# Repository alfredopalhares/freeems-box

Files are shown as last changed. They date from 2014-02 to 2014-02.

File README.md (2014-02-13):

FreeEMS Box
===========

A Case to host the FreeEMS capabable boards, to keep all that deterministic horse power safe !

Supported Boards
----------------

- [Jaguar](https://github.com/DeuceEFI/Jaguar) Work in progress

License
-------

The License is [MIT](http://opensource.org/licenses/MIT) with a flavour of beerware, if you use this
this you *must* pay me a beer or you shall be cursed by the Gods of Speed :)

Authors and Copyright
---------------------

- Alfredo Palhares (masterkorp@masterkorp.net) and masterkorp on irc.freenode.org

The molex connectors data sheets and all the related informations is copyright of Molex, Inc.

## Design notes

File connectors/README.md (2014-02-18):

Connectors
----------

The connectors used are the [Molex XRC](http://www.molex.com/molex/products/family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) due to its rugged construction and panel like mounting facility.

The parts

## Plug, 31 circuits
Part ID: [0845050003](http://www.molex.com/molex/products/datasheet.jsp?part=active/0845050003_CRIMP_HOUSINGS.xml)
[Datasheet](http://www.molex.com/elqNow/elqRedir.htm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)
[Drawing](http://www.molex.com/elqNow/elqRedir.htm?ref=http://www.molex.com/pdm_docs/sd/845050003_sd.pdf)
[Product Specification](http://www.molex.com/elqNow/elqRedir.htm?ref=http://www.molex.com/pdm_docs/ps/PS-84501-001.pdf)

## Pins for the plug
The pins can be of the [84524 Sealed Pins](http://www.molex.com/molex/products/listview.jsp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)

## Receptor, 31 circuits
Part ID: [845060001](http://www.molex.com/molex/products/datasheet.jsp?part=active/0845060001_CRIMP_HOUSINGS.xml)
[Datasheet](http://www.molex.com/elqNow/elqRedir.htm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)
[Drawing](http://www.molex.com/elqNow/elqRedir.htm?ref=http://www.molex.com/pdm_docs/sd/845060001_sd.pdf)
[Product Specification](http://www.molex.com/elqNow/elqRedir.htm?ref=http://www.molex.com/pdm_docs/ps/PS-84501-001.pdf)

## Sockets for the Plug
The sockets can be any of [84525 Sealed Sockets](http://www.molex.com/molex/products/listview.jsp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)

## Hex nut for the rececptor
Allowing the the receptor to be fixed into the case panel style
Part ID: [845060012](http://www.molex.com/molex/products/datasheet.jsp?part=active/0845060012_ACCESSORIES.xml)
[Datasheet](http://www.molex.com/elqNow/elqRedir.htm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)
[Drawing](http://www.molex.com/elqNow/elqRedir.htm?ref=http://www.molex.com/pdm_docs/sd/845060012_sd.pdf)

## Panel gasket for the receptor
To make it water proof
Part ID [845060062](http://www.molex.com/molex/products/datasheet.jsp?part=active/0845060062_ACCESSORIES.xml)
[Datasheet](http://www.molex.com/elqNow/elqRedir.htm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)
[Drawing](http://www.molex.com/elqNow/elqRedir.htm?ref=http://www.molex.com/pdm_docs/sd/845060062_sd.pdf)

## Backshell for Plug and receptable
You should use one for the plug to keep the wiring tidy.
Part ID [84537-0003](http://www.molex.com/molex/products/datasheet.jsp?part=active/0845370003_ACCESSORIES.xml)

## USb waterproof connector
The part is from USBfirewire
Part ID: [RR-111200-10](http://www.usbfirewire.com/Parts/rr-111200-10.html)
It the includes the hex nut and the seal gasket on the kit.

## Dust cover for the usb
The IP67 rated rap
Part ID: [RR-1C542122](http://www.usbfirewire.com/Parts/rr-1c542122.html)

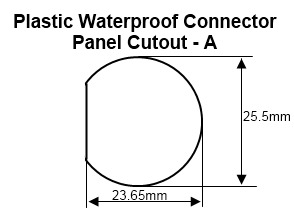
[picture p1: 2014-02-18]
connectors/usb_RR-111200-10/cutoff_diagram.png

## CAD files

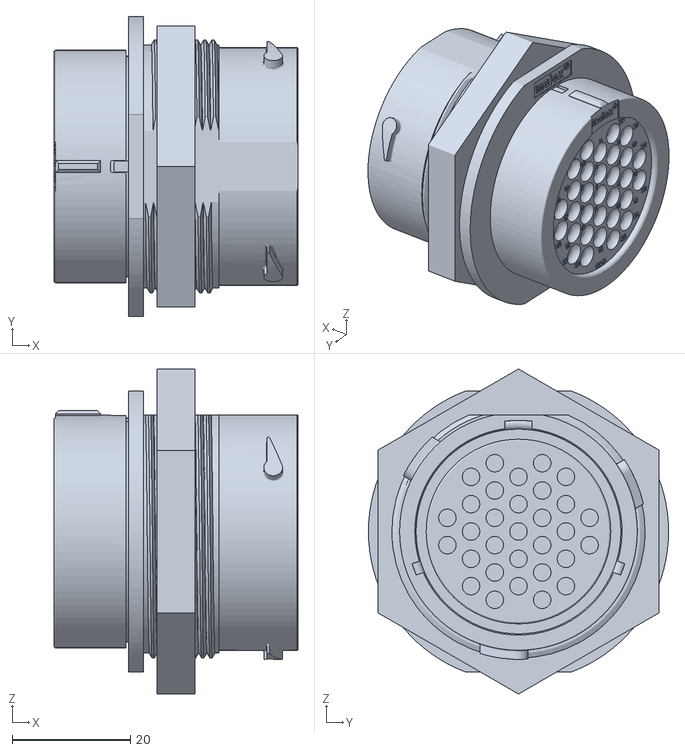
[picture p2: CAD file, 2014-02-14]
connectors/receptor_084506001/molex_receptor.stl
41.3 x 50.8 x 55.0

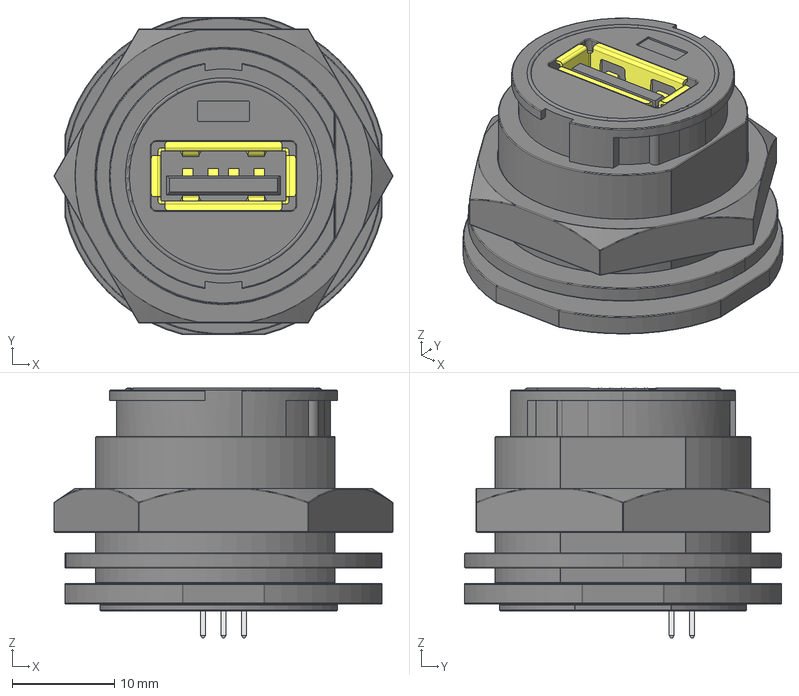
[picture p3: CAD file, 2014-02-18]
connectors/usb_RR-111200-10/RR-111200-10.stp
33.1 x 31.0 x 24.4 mm

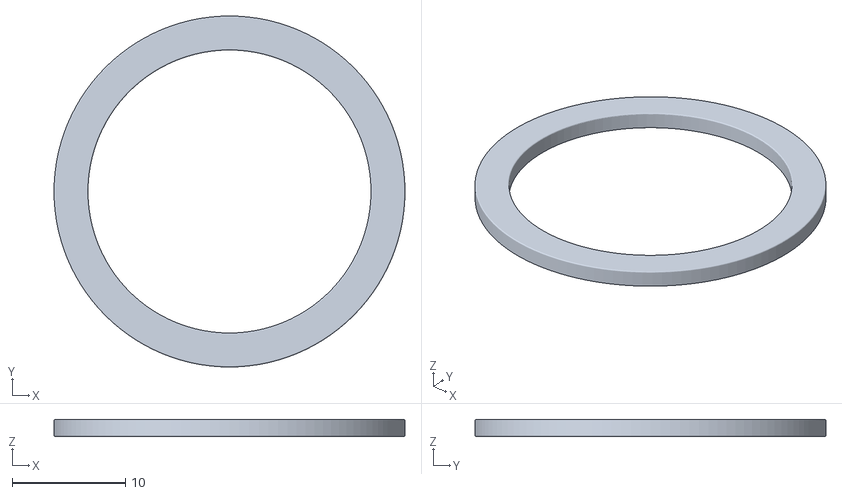
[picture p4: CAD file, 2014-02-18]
connectors/usb_RR-111200-10/rubber_gasket.stl
31.0 x 31.0 x 1.50

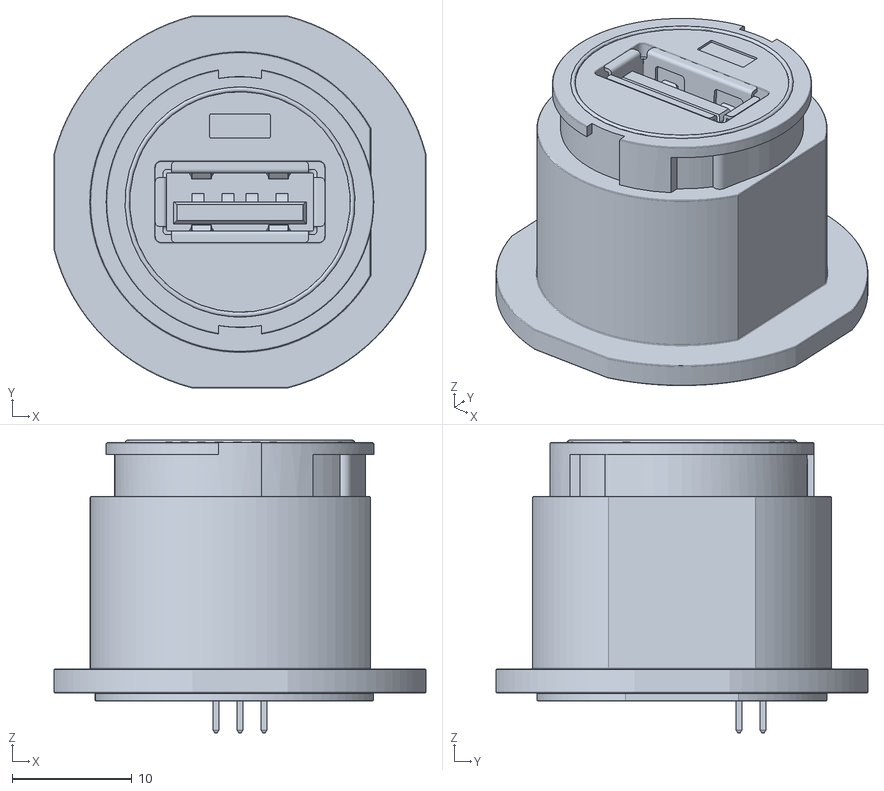
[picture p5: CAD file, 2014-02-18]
connectors/usb_RR-111200-10/usb_receptor.stl
31.0 x 31.0 x 24.4

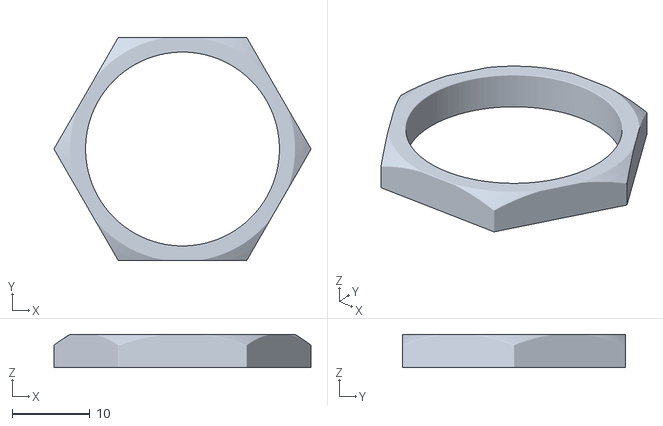
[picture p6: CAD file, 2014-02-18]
connectors/usb_RR-111200-10/hex_nut.stl
33.1 x 28.7 x 4.30

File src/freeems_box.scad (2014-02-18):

include <jaguar.scad>;
include <BOLTS/BOLTS.scad>;
include <molex_mount.scad>;
include <usb_mount.scad>;


// Units are milimeters

//Assembly mode
ASSEMBLY=false;

//GLOBALS
HEIGHT=60; // Z
WIDTH=150; // Y
LENGTH=200; // X
THICKNESS=5;

// The size that connector occupies inside the case
molex_non_thread_size = (46.9 - 26.2);

difference() {
  cube(size = [LENGTH, WIDTH, HEIGHT], center = true);
  translate([0, 0,  THICKNESS]) {
    cube(size = [(LENGTH - THICKNESS),  WIDTH - THICKNESS, HEIGHT + 1], center=true);
  }
  // Jaguar slice to fit one side of the board
  translate([0,76.2/2 - (THICKNESS - 2) , 0]) {
    jaguar();
  }

  // Molex mounting
  translate([-(LENGTH/3),0, 0] ){
    translate([0, -(WIDTH/2 - molex_non_thread_size + 1), 0]) {
      molex_mount();
    }
  }
  translate([0, -(WIDTH/2 - molex_non_thread_size + 1), 0]) {
    molex_mount();
  }
  translate([(LENGTH/3),0, 0] ){
    translate([0, -(WIDTH/2 - molex_non_thread_size + 1), 0]) {
      molex_mount();
    }
  }

  // Usb mounting
  translate([-(LENGTH/2 + 1),0,0]) {
    rotate([0,90, 90]) {
      usb_mount();
    }
  }
}

// Inner mounting device for the jaguar
difference() {
  translate([0, -5, -HEIGHT/4]) {
    cube(size = [127 + 20, 10, HEIGHT/2], center = true);
  }
  // Jaguar slice to fit the center side of the board
  translate([0,76.2/2 - (THICKNESS - 2) , 0]) {
    jaguar();
  }

}


if (ASSEMBLY == true) {
  translate([0,76.2/2 - (THICKNESS - 2) , 0]) {
    jaguar();
  }
  molex_receptor();
  translate([LENGTH/3, 0, 0]) {
    molex_receptor();
  }
  translate([LENGTH * (2/3), 0, 0]) {
    molex_receptor();
  }
  translate([-(LENGTH/2 - 5), 0, 0]) {
    rotate([-90,0,90]) {
      usb_receptor();
      translate([0,0,2]) {
        usb_gasket();
      }
      usb_hex_nut();
    }
  }
}

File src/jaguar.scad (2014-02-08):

/* Place holder for the jaguar board
   Size is 3x5 inches
   The thickness is 1.6 give it more for good fit */

module jaguar() {
  color("Blue") {
    cube(size = [127, 76.2, 1.9], center=true);
  }
}

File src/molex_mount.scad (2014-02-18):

// A hole to fit the molex rececptor ID 84506-0001

module molex_diagram() {
  // Dimmensions, check the drawing on the connectors folder
  diameter=43.08;
  height=41.45;
  color("Grey") {
    intersection() {
      circle(r = diameter/2, center = true);
      // We only need the top to be cut
      translate([0, -(diameter - height), 0]) {
        square([diameter, height], center = true);
      }
    }
  }
}

module molex_mount() {
  color("Red") {
  // Space that the molex should take inside the case
    rotate([90, 0, 0]) {
      linear_extrude(molex_non_thread_size) {
        molex_diagram();
      }
    }
  }
}

/* The reprentation of the molex recptor
 * Frecad generares the stl according to the angle you create the
 * So the mesh needs to be rotate and translated to a suitable place
 * This goes to the first hole
 */
module molex_receptor() {
  rotate([0, 0, 270]) {
    // Points to the left molex hole.
    translate([30, -500, 0]) {
      color("Grey") {
        import("../connectors/receptor_084506001/molex_receptor.stl");
      }
    }
  }
}

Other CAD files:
src/usb_mount.scad
src/BOLTS/BOLTS.scad
src/BOLTS/BOLTS_ANSI.scad
src/BOLTS/BOLTS_ASME.scad
src/BOLTS/BOLTS_DIN.scad
src/BOLTS/BOLTS_DINEN.scad
src/BOLTS/BOLTS_DINENISO.scad
src/BOLTS/BOLTS_DINISO.scad
src/BOLTS/BOLTS_EN.scad
src/BOLTS/BOLTS_ISO.scad
src/BOLTS/base/bearings.scad
src/BOLTS/base/hex.scad
src/BOLTS/base/hex_socket.scad
src/BOLTS/base/nut.scad
src/BOLTS/base/pipe.scad
src/BOLTS/base/washer.scad
src/BOLTS/common/common.scad
src/BOLTS/common/conf.scad
src/BOLTS/common/version.scad
src/BOLTS/tables/axialthrustbearing_table.scad
src/BOLTS/tables/din11850range2_table.scad
src/BOLTS/tables/heavydutyplainwasher_table.scad
src/BOLTS/tables/hexagonnut1_table.scad
src/BOLTS/tables/hexagonnut2_table.scad
src/BOLTS/tables/hexagonnut3_table.scad
src/BOLTS/tables/hexagonthinnut1_table.scad
src/BOLTS/tables/hexagonthinnut2_table.scad
src/BOLTS/tables/hexbolt1_table.scad
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

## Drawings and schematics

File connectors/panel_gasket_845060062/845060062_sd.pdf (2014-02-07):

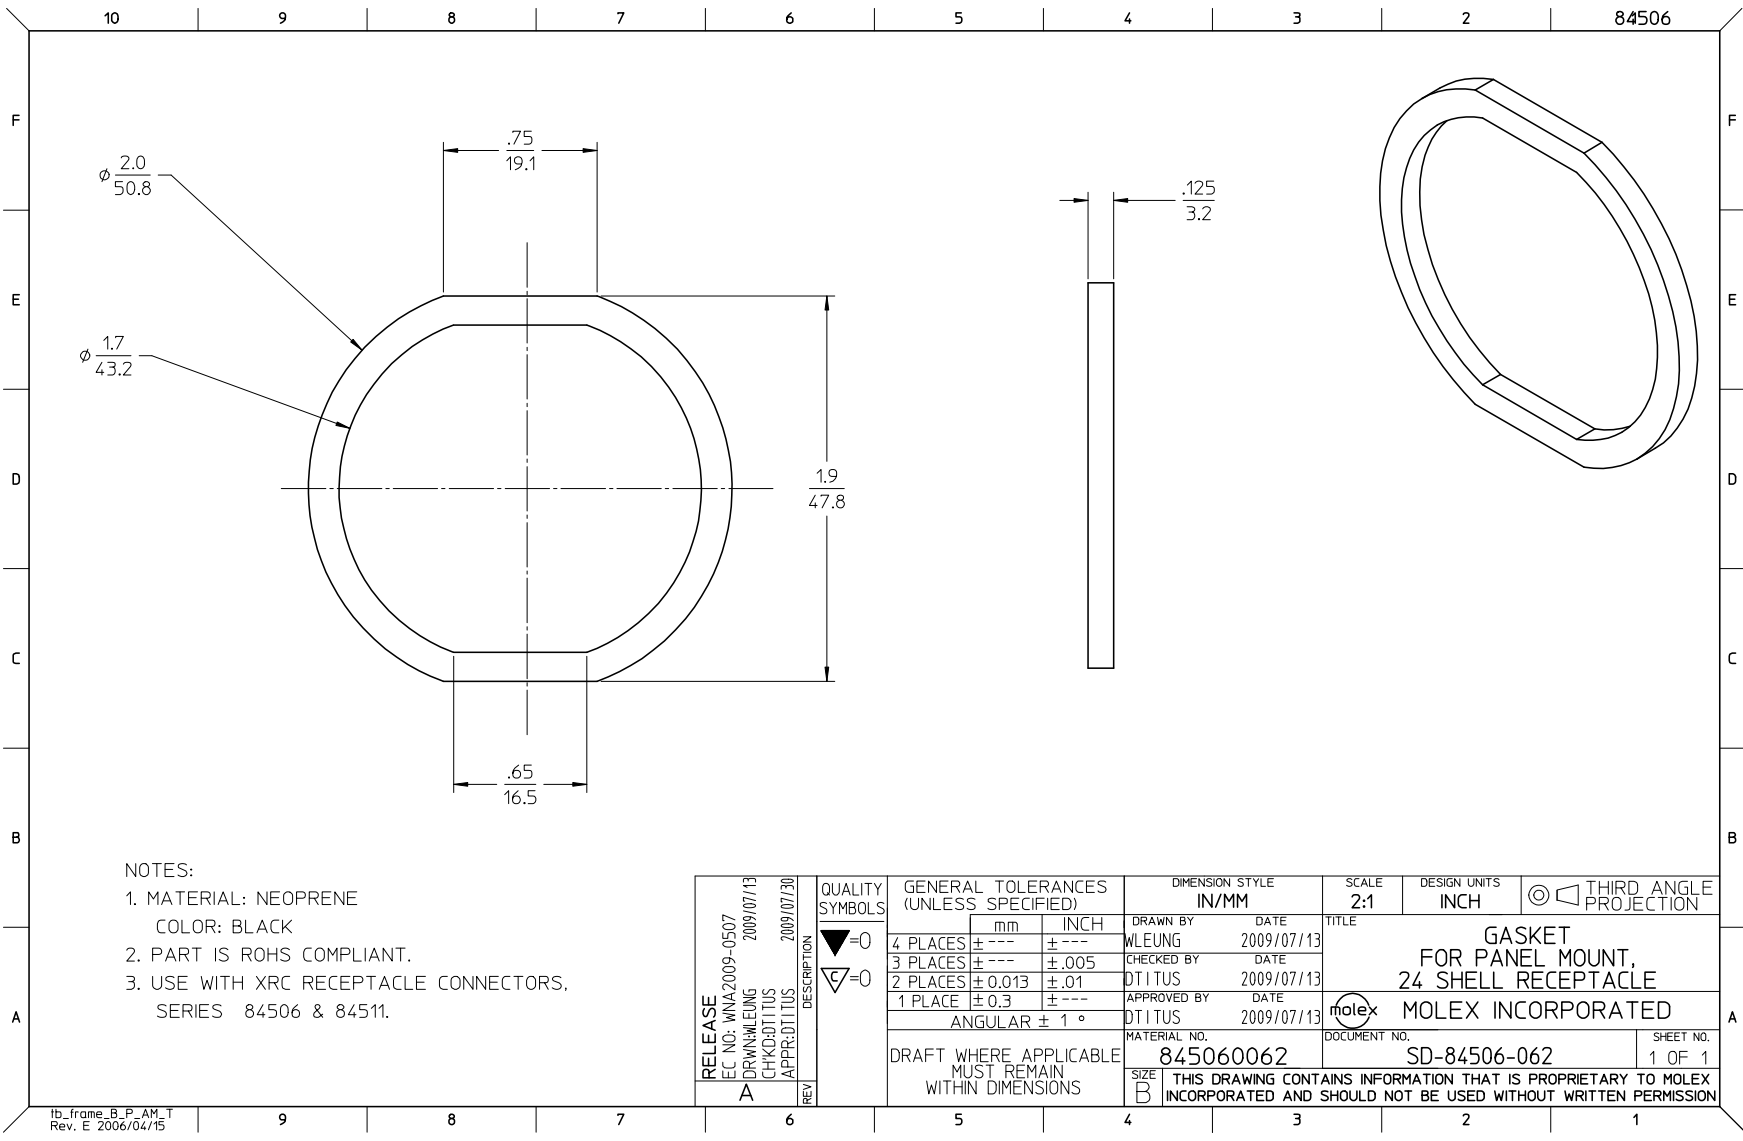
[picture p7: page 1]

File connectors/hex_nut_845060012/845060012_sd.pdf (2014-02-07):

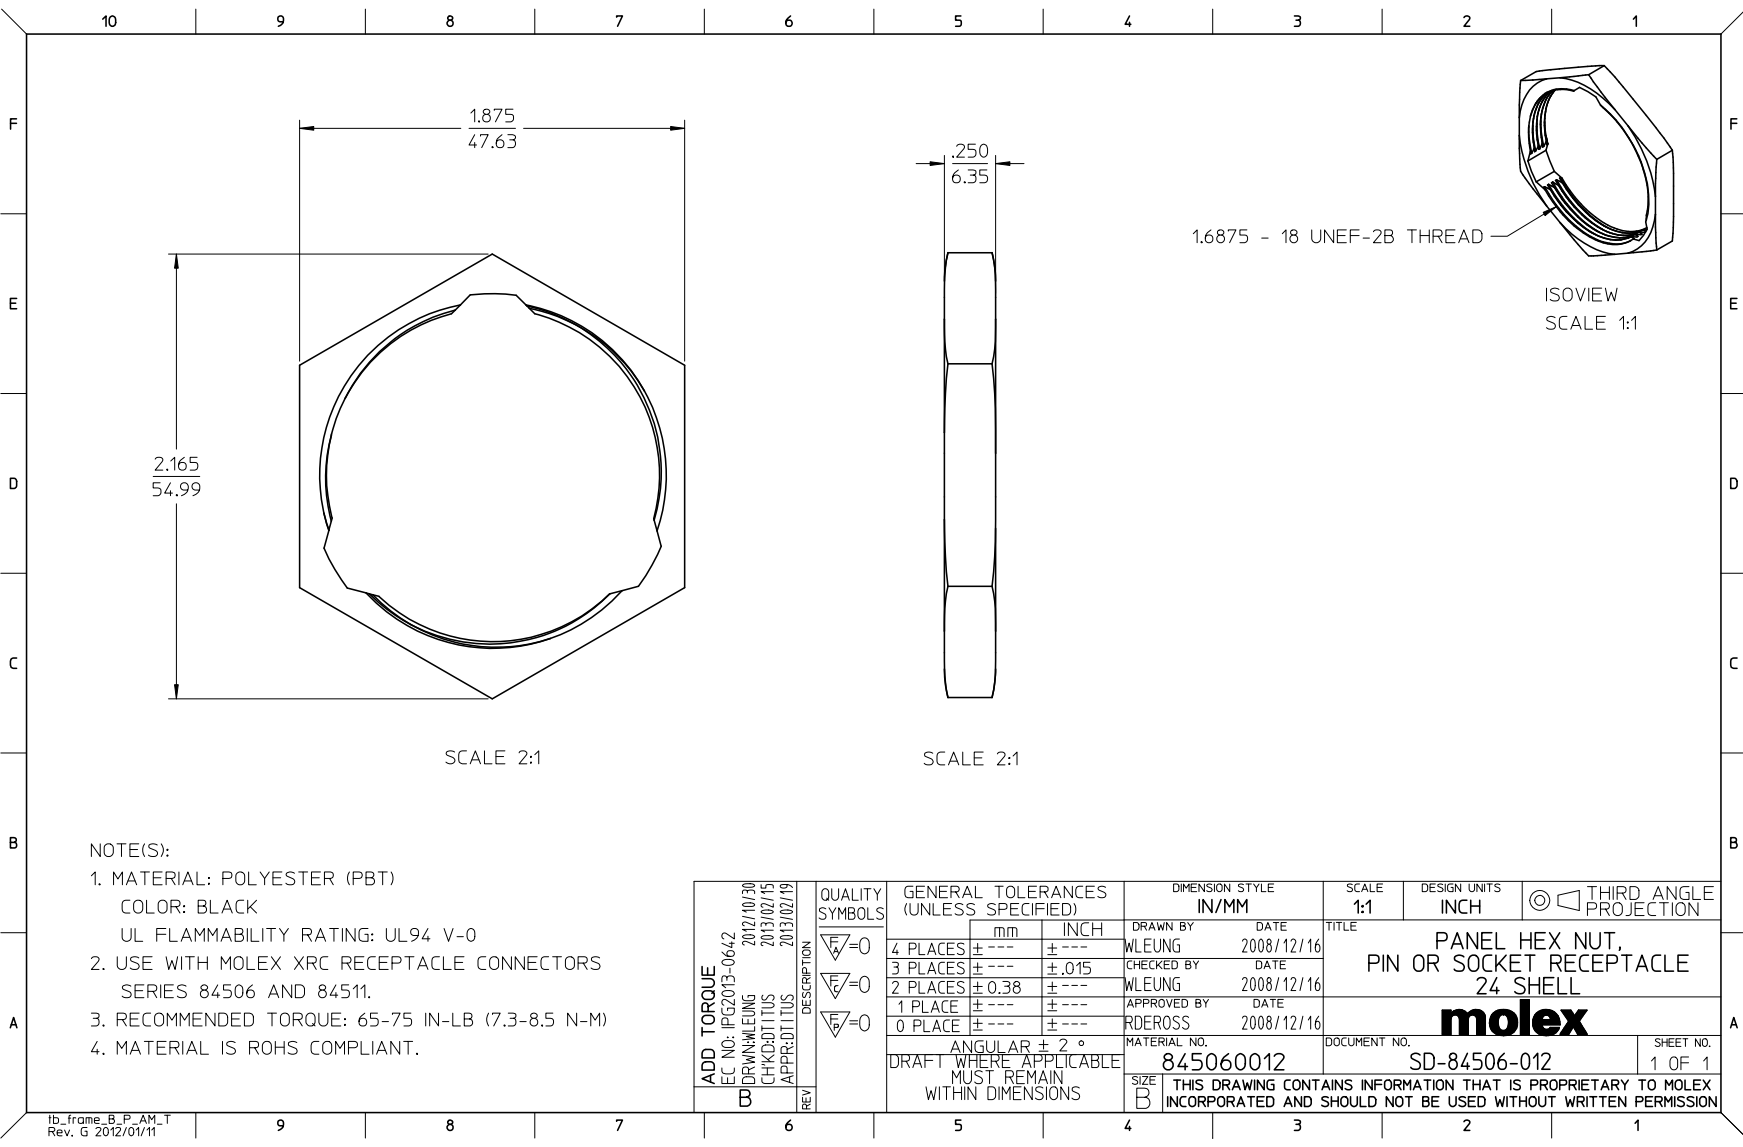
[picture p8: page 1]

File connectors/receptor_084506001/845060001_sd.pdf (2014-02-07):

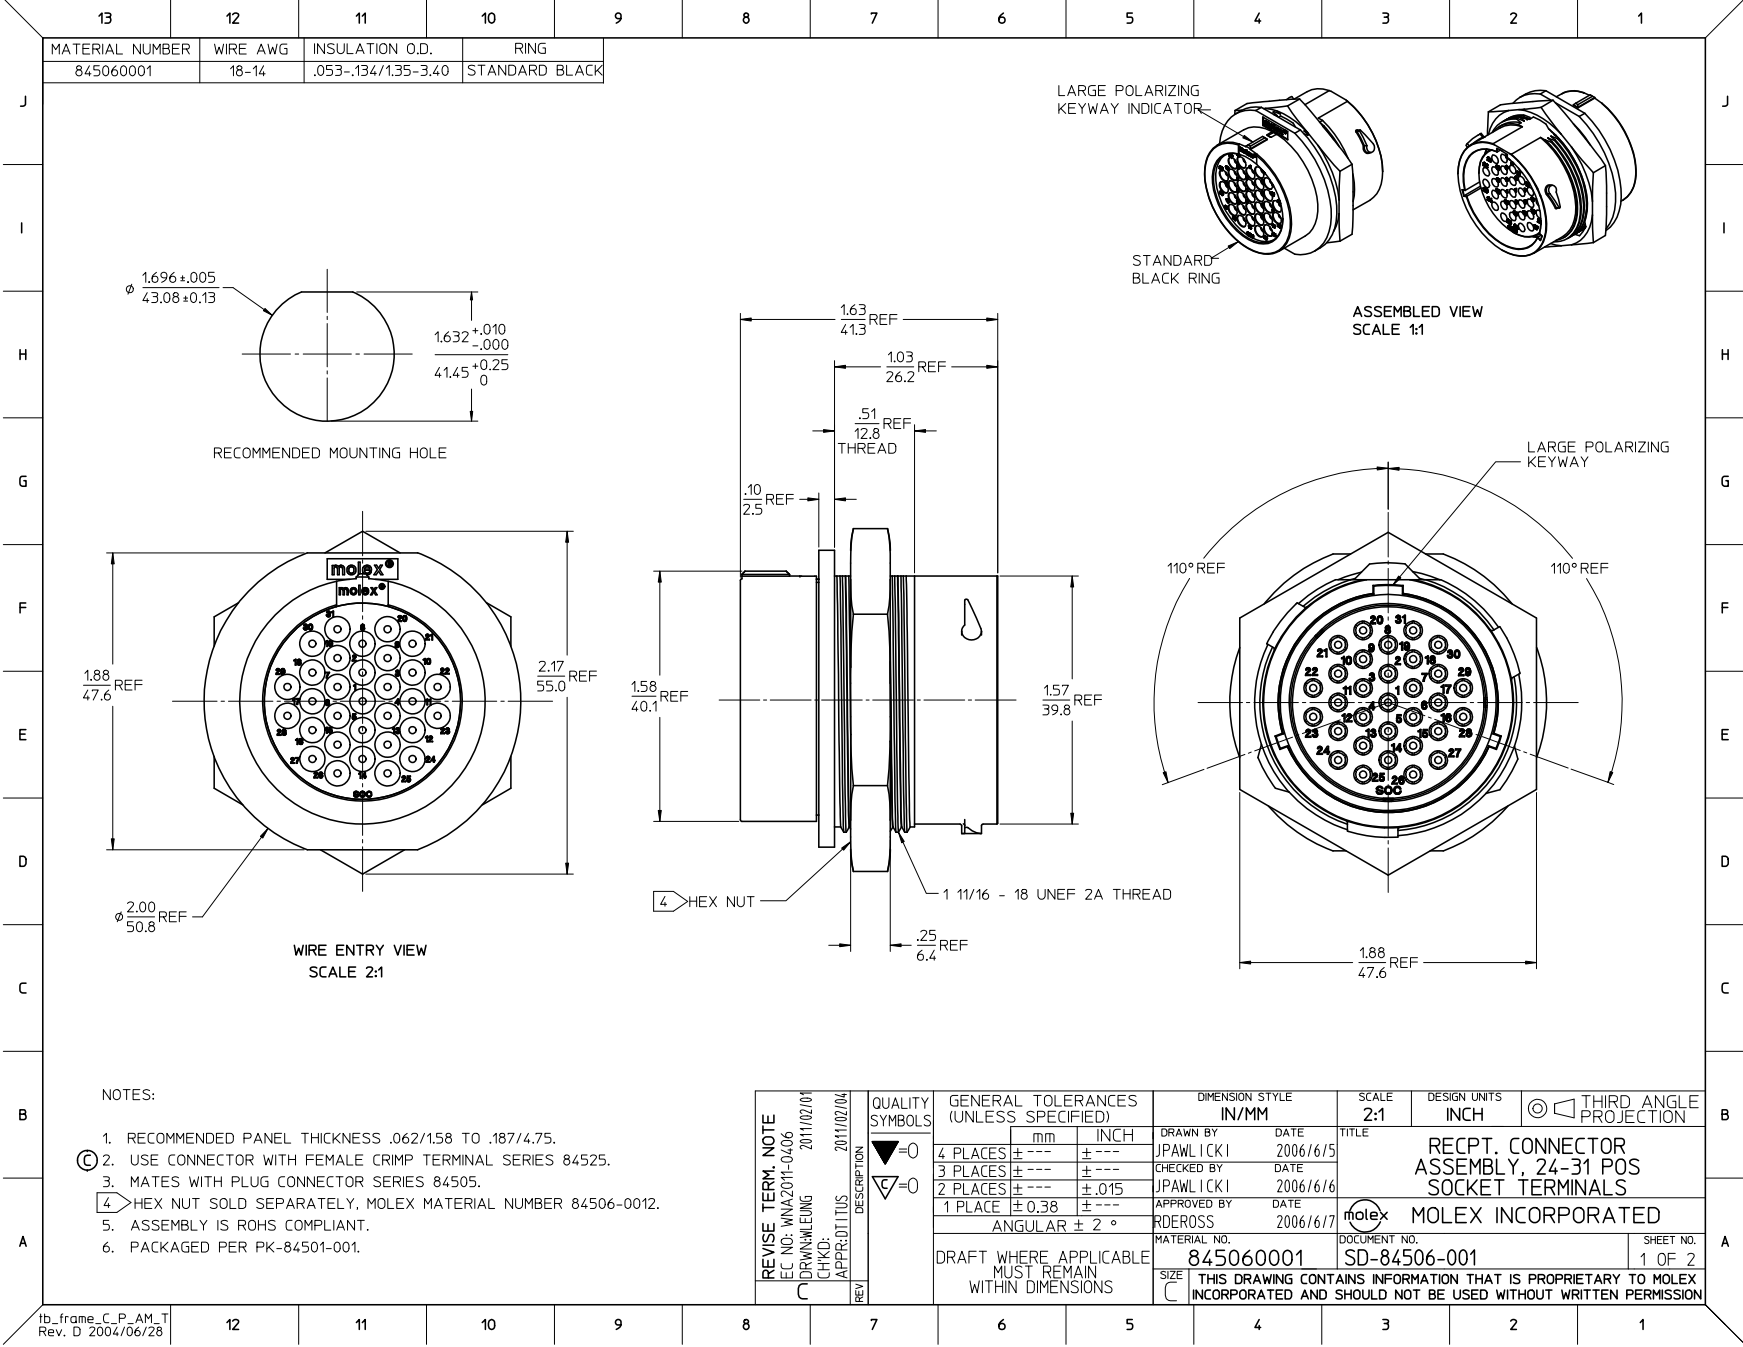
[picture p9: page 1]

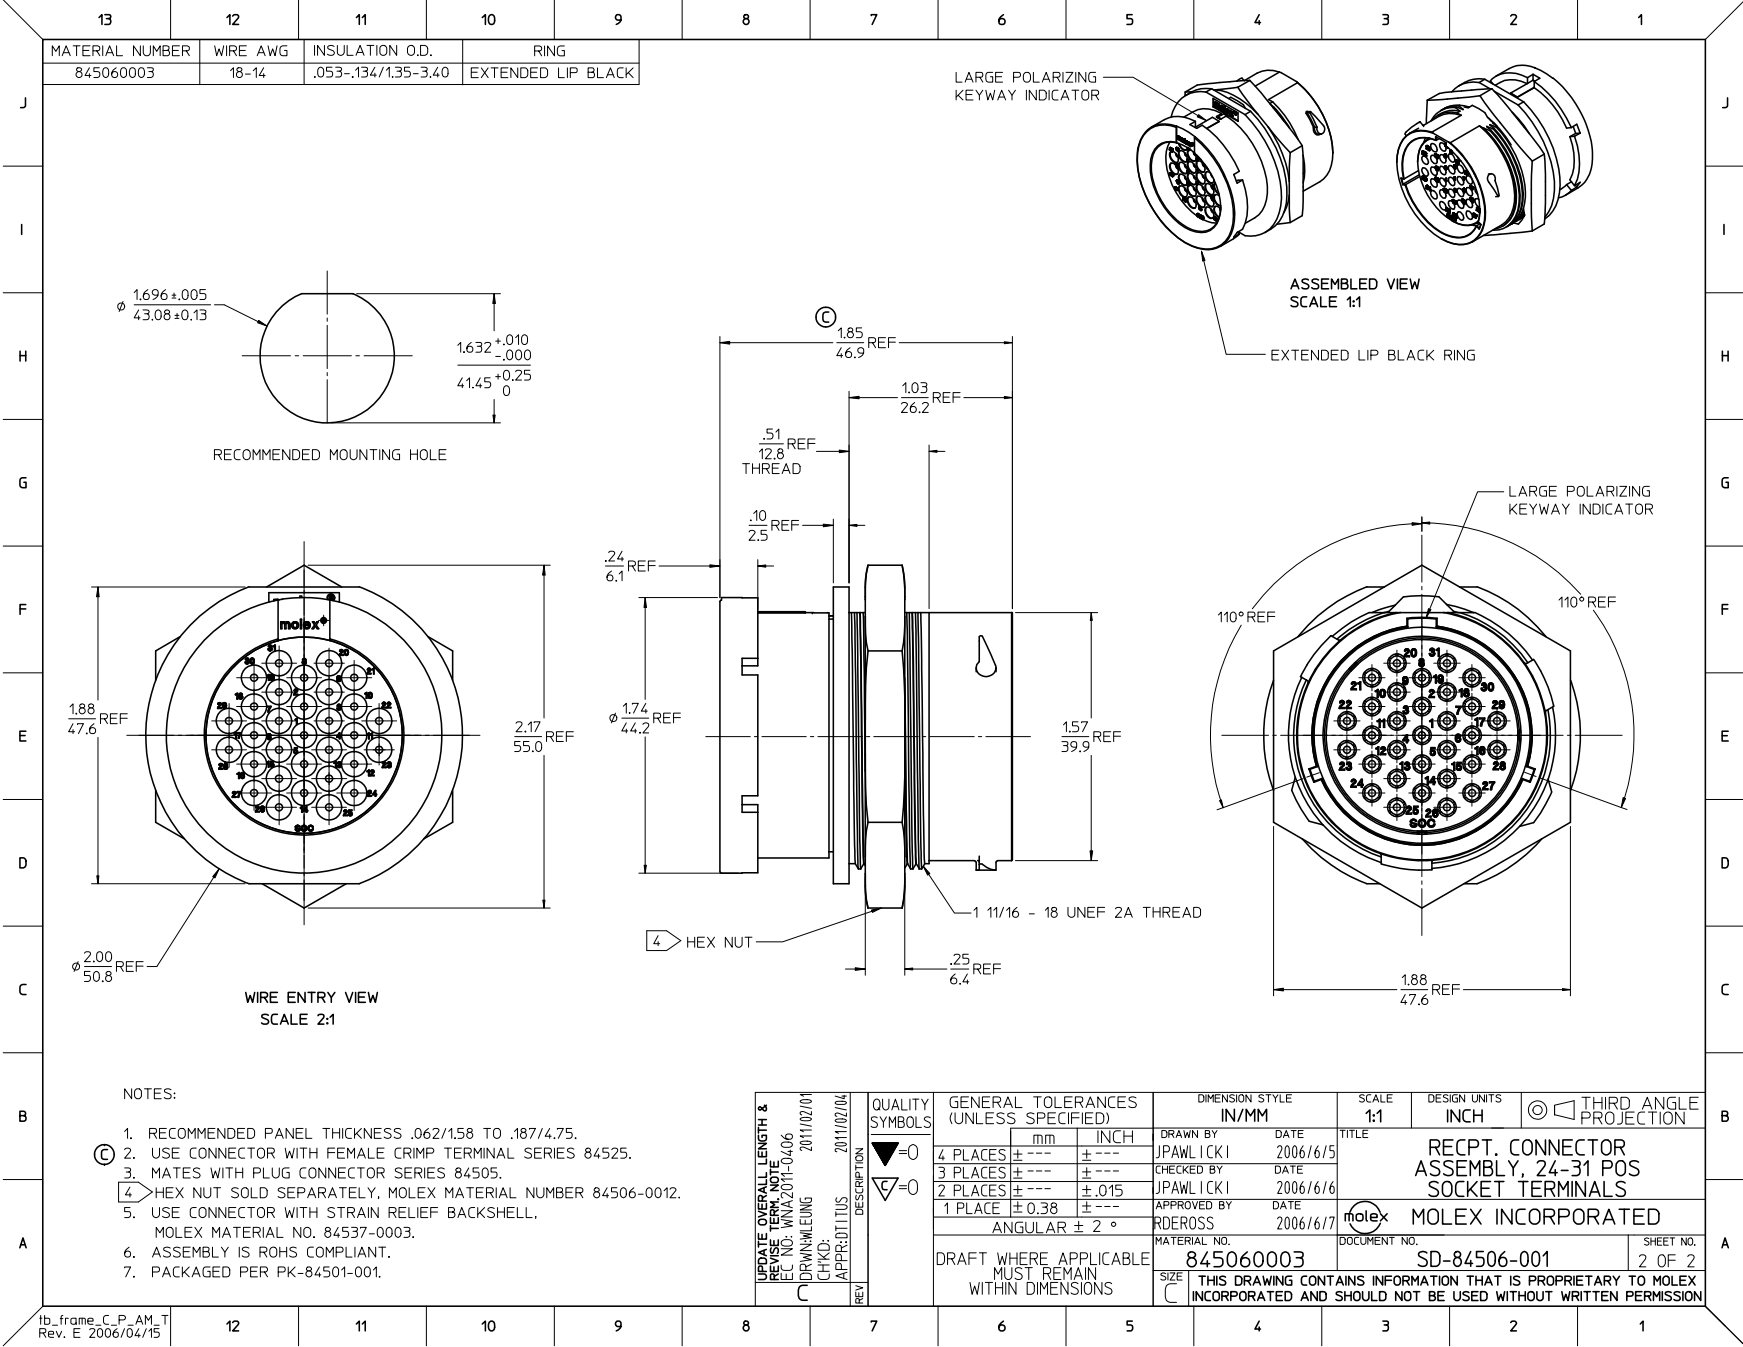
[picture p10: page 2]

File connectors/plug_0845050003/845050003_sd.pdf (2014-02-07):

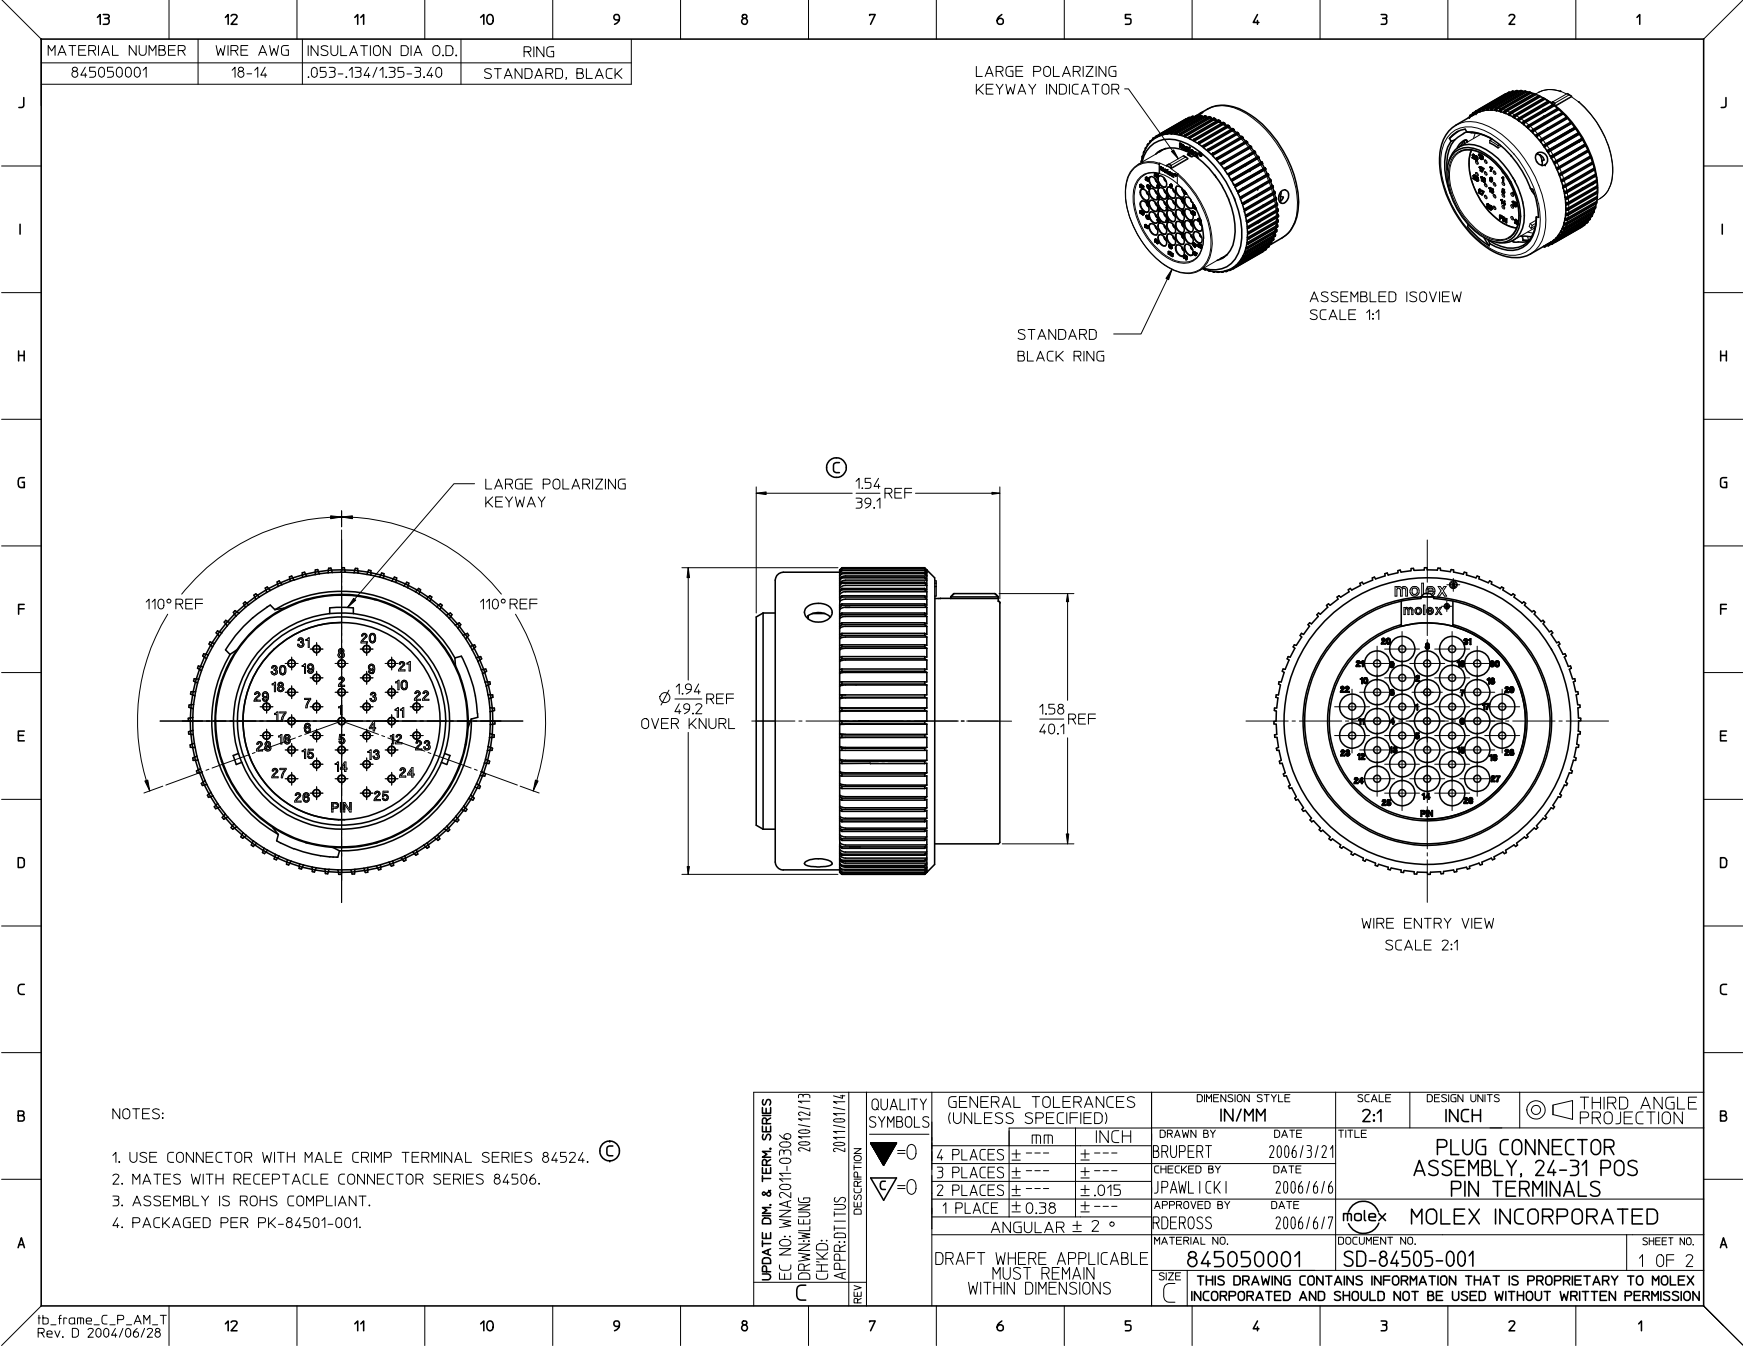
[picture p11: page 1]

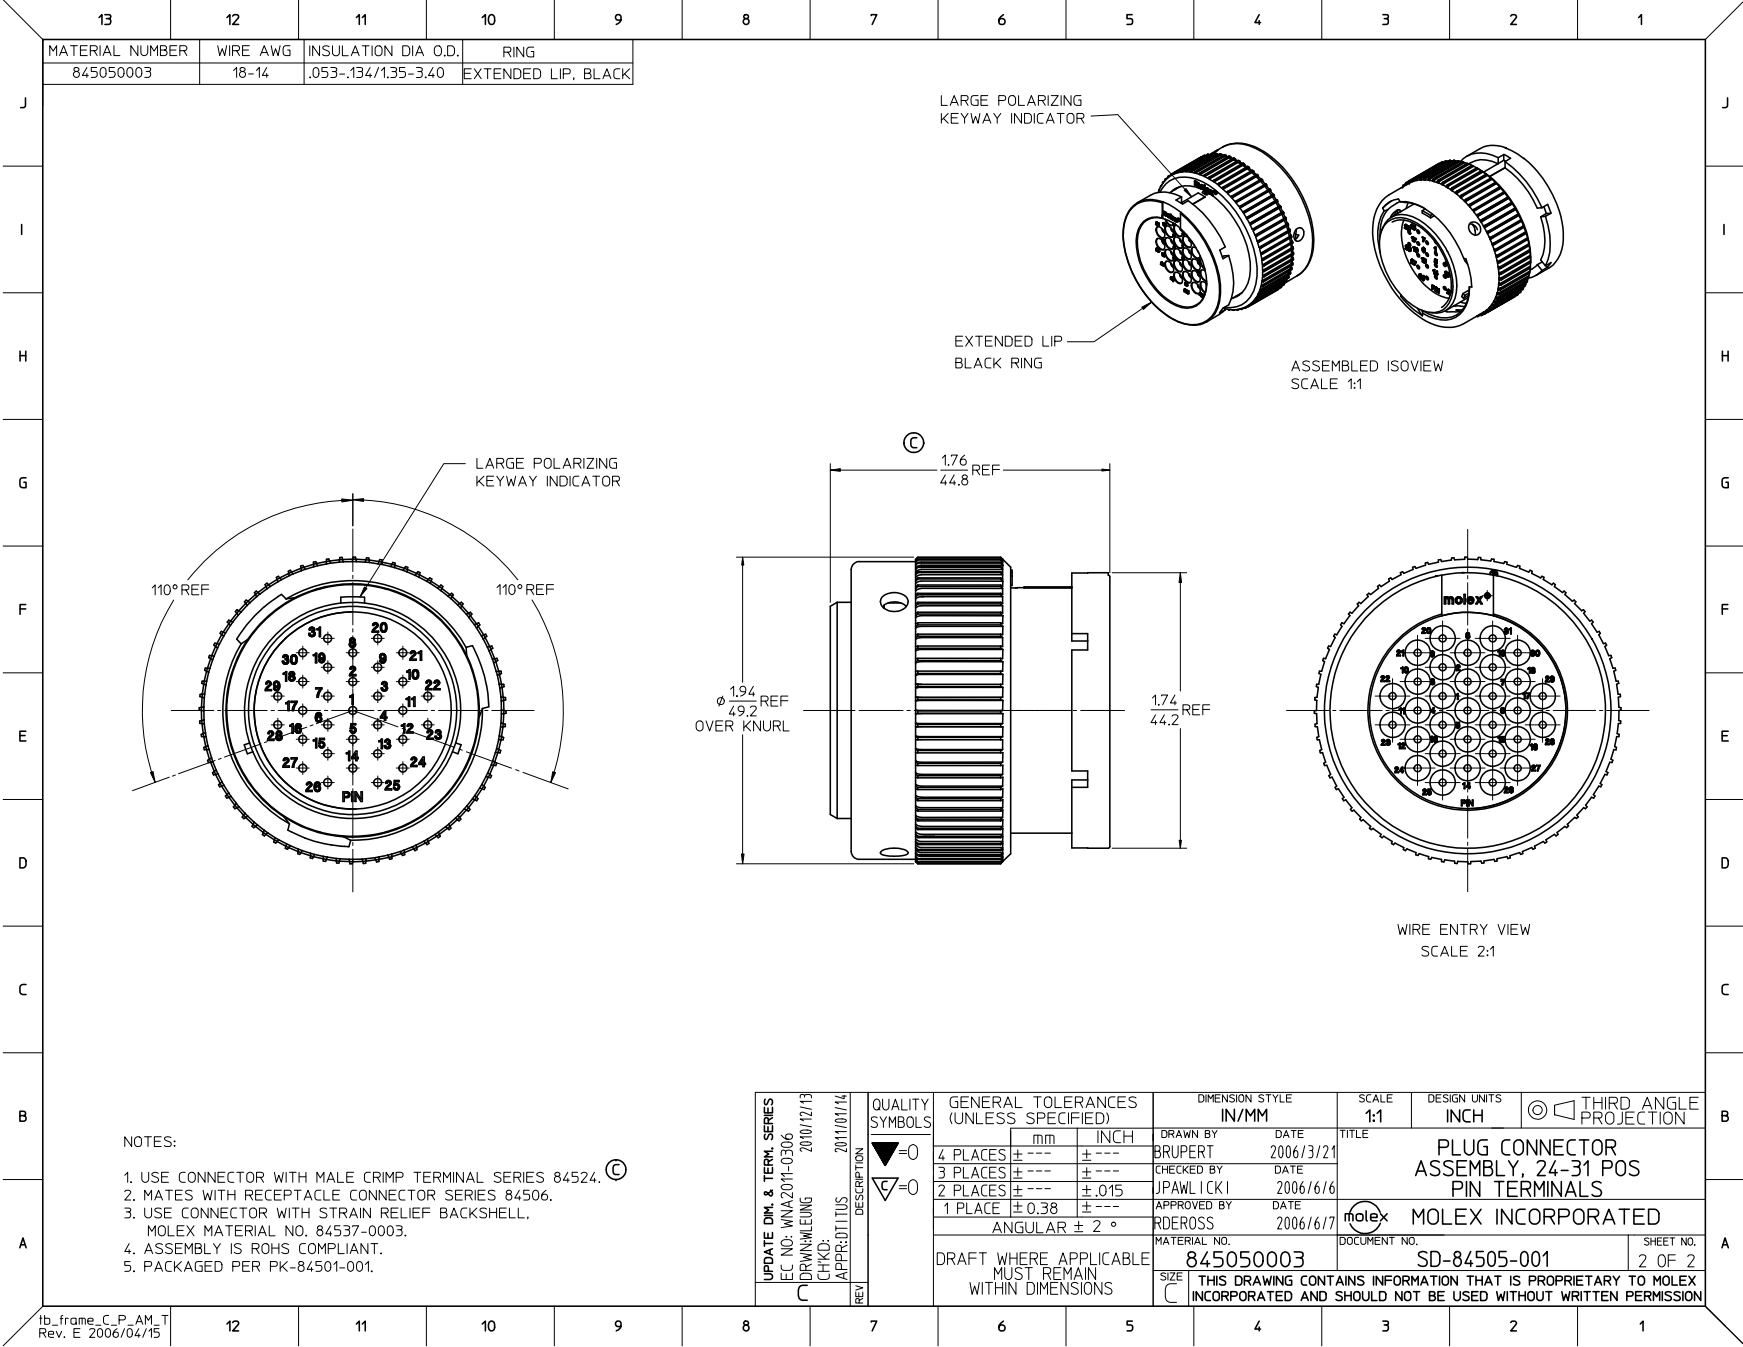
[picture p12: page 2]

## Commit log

2014-02-07 Molex 0845050003 Connector product specification.
2014-02-07 Molex 08405003 Recepect CAD step file.
2014-02-07 Molex 084506001 rececpt datasheet, drawing, specs and STEP CAD.
2014-02-07 Molex 845060012 Hex Nut for the recepct datasheet and drawing.
2014-02-07 Documentation about the connectors used on the case.
2014-02-08 A stub. We can already see how much size the jaguar board will take.
    [freeems_box.scad, jaguar.scad]
2014-02-12 Use the Bolts Library version 1.2.1
    [BOLTS.scad, BOLTS_ANSI.scad, BOLTS_ASME.scad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]
2014-02-12 Slice on the wall to mount one side of the jaguar board.
    [freeems_box.scad]
2014-02-13 Jaguar mounting devices stub. Using a slice on the side of the case.
    [freeems_box.scad]
2014-02-13 Set an assembly mode to show the empty box or a visualization of how the box is gonna be.
    [freeems_box.scad]
2014-02-13 Freecad generated STL file of the molex receptor.
    [molex_receptor.stl]
2014-02-13 Typo fix.
    [molex_receptor.stl]
2014-02-13 Import the molex recpetor from the new path.
    [freeems_box.scad]
2014-02-13 Remove box color for now, its easier to visualize it by now.
    [freeems_box.scad]
2014-02-13 Diagram of the Molex Recpector mounting.
    [molex_mount.scad]
2014-02-13 The mounting hole representation on the case.
    [freeems_box.scad]
2014-02-14 Refactor the molex mount.
    [freeems_box.scad, molex_mount.scad]
2014-02-14 Translate the mount to the correct position.
    [freeems_box.scad]
2014-02-14 Add left molex mount.
    [freeems_box.scad]
2014-02-14 Right molex receptor mount.
    [freeems_box.scad]
2014-02-14 Set case height to 60 milimetres, allowing the molex connectors to easly fit.
    [freeems_box.scad]
2014-02-14 Regenerate the stl from another angle.
    [molex_receptor.stl]
2014-02-14 Molex recpetor module.
    [molex_mount.scad]
2014-02-14 Represent the molex receptors on the mounts.
    [freeems_box.scad]
2014-02-15 Information about the usb connector and the diagram.
2014-02-15 Usb connector cutoff diagram.
2014-02-18 Diagram of the usb connector cutoff. Based on the diagram.
    [usb_mount.scad]
2014-02-18 Step file kindly provided by USBFireWire.
    [RR-111200-10.stp, usb_mount.scad]
2014-02-18 STL generated file on FreeCAD from the usb receptor.
    [usb_receptor.stl]
2014-02-18 STL file generated from FreeCAD of the rubber gasket.
    [rubber_gasket.stl]
2014-02-18 STL file generated from FreeCAD of the looking nut of the usb receptor.
    [hex_nut.stl]
2014-02-18 Representation of the cutoff and the STL of the USBFireWire USB receptor.
    [usb_mount.scad]
2014-02-18 Include USB mount file.
    [freeems_box.scad]
2014-02-18 The panel hole for the USB receptor.
    [freeems_box.scad]
2014-02-18 USB Receptor Assembly representation.
    [freeems_box.scad]
2014-02-18 Trailing space fix.
    [molex_mount.scad]
2014-03-13 Finish usb representation.
    [RR-111200-10.stp, hex_nut.stl, molex_mount.scad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]
2014-03-13 FreeCAD genetared STL files based on the Provided USBFireWire STEP file.
    [RR-111200-10.stp, hex_nut.stl, rubber_gasket.stl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]
